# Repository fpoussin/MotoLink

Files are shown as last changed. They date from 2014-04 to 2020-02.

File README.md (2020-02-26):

View this project on [CADLAB.io](https://cadlab.io/node/808). 

MotoLink
===================

 
Build Status (https://jenkins.netyxia.net/job/MotoLink/job/master/) 
 
  

CAN Bus, K-Line interface for motorcycles, with a fuel/ignition mapper function.  

Primarily intended to communicate with Honda HRC, Generic OBD, or Yamaha YEC ECUs.  

This device will create a fuel map based on the various sensor inputs. You will then be able to alter the fuel using your prefered application. (HRC, TuneEcu, YEC, etc...)  
This replaces auto tune fuel systems like Bazzaz or Power commander, except you still have to enter the changes manually. (import/export functions are planned)  
Having a wideband exhaust sensor is mandatory. If your bike doesn't have one, you can use an innovate LC2.  

Includes some digital (RPM, Speed), analog (TPS, ECT, Wideband), serial (Wideband), as well as a knock sensor input interface for tuning.



(https://www.youtube.com/watch?v=rAnS-8KSQrY)

### File tree:  
**├── Board**  *Eagle board files*  
**├── Code**  
**│   ├── App**  *Motolink's MCU code*  
**│   ├── Bootloader**  *STM32 Bootloader*  
**│   ├── ChibiOS-RT**  *ChibiOS/RT submodule*  
**│   ├── ChibiOS-Contrib**  *ChibiOS Community drivers submodule*  
**│   └── Common**  *Common files for bootloader and Motolink*  
**├── Drivers**  *Windows drivers installer*  
**├── GUI**  *Motolink's graphical user interface*  
**├── LICENSE**  *GPL Licence file*  
**└── README.md**  *This readme file*  

You will need to init and update the git submodules (QtUsb, ChibiOS-RT, ChibiOS-Contrib) to build the projects.

## Building
### GUI
* Make sure submodules are pulled
* You will need python 2/3 in the path (system path or Qt Creator project setting PATH variable)
* Go to the GUI folder
* Unzip res/oxygen.zip
* You need a binary file of the firmware, an empty one can be created for testing. (../code/app/build/motolink.bin)
* You need to install QtUsb (https://github.com/fpoussin/QtUsb)
* Open the project with Qt Creator
* Compile and launch

### App and Bootloader
* [You will need ARM's GCC toolchain](https://developer.arm.com/open-source/gnu-toolchain/gnu-rm/downloads)
* Make sure submodules are pulled
* Go the de code/app or code/bootloader folder
* For the app, you need to compile the DSP lib (just launch make in the dsp_lib folder)
* make
* For the bootloader, use your favorite stlink interface [or my QSTLink2 app](https://github.com/fpoussin/QStlink2)
* Once the bootloader is running, you can update the app through the GUI

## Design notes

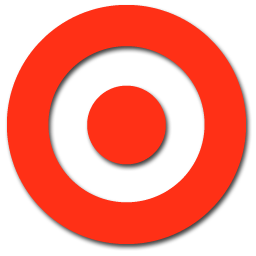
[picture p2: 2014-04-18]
GUI/res/images/target.png

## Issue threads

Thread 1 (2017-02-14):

more documentation please?

rusefi, 2017-02-14:
I've read the title page https://github.com/fpoussin/MotoLink but I am still not sure what this is and what is the status of this project.

Is this an auto-tuning software with an stm32 device as a CAN bridge? What CAN protocols do you currently support?

fpoussin, 2017-02-14:
It's an interface for aftermarket motorcycle (but works for cars too) ECU. It allows for auto mapping while looking for AFR and knock, there's a LIN interface for Hondas, the CAN interface is for some other brands but I haven't tested it (except hardware) so it's unused.

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

rusefi, 2017-02-15:
Can you please elaborate on CAN firmware capabilities? I am interested to learn more about specific protocols.

Is it untested because you do not have a CAN vehicle to test with? My truck has CAN OBD.

fpoussin, 2017-02-15:
Right now there is none as my race bike ECU (Honda) does not communicate at all during run, I use signals from the sensors directly. It have plans to test it on a modern Yamaha (MT-10) which uses a specific protocol. I also need to test on OBD CAN. (maybe on a simulator)

rusefi, 2017-02-15:
Can you point me at your OBD code?

fpoussin, 2017-02-15:
As I said it's not there yet (except basic init of the peripheral)
Sadly I don't have CAN on my car...

You can have a look at some other code here: https://github.com/ObdDiag-Net/allpro/blob/master/src/adapter/obd/isocan.cpp
https://github.com/brendan-w/python-OBD/blob/master/obd/protocols/protocol_can.py
https://en.wikipedia.org/wiki/OBD-II_PIDs#CAN_.2811-bit.29_bus_format

It's mostly a matter of setting the CAN filters, sending PIDs an reading the answer, it should be easy.

rusefi, 2017-02-15:
Thank you! Will check these links.

PS: just to be pedantic - the way I read it sounded as "not tested".

fpoussin, 2017-02-16:
You're welcome!

I'll add some code for the CAN protocols soon but I have no way to test it on a car, I also need to get an adapter to reverse engineer Yamaha's protocol.

fpoussin, 2017-02-16:
I added some basic canbus code here if you want to check.
https://github.com/fpoussin/MotoLink/blob/master/code/app/canbus.c

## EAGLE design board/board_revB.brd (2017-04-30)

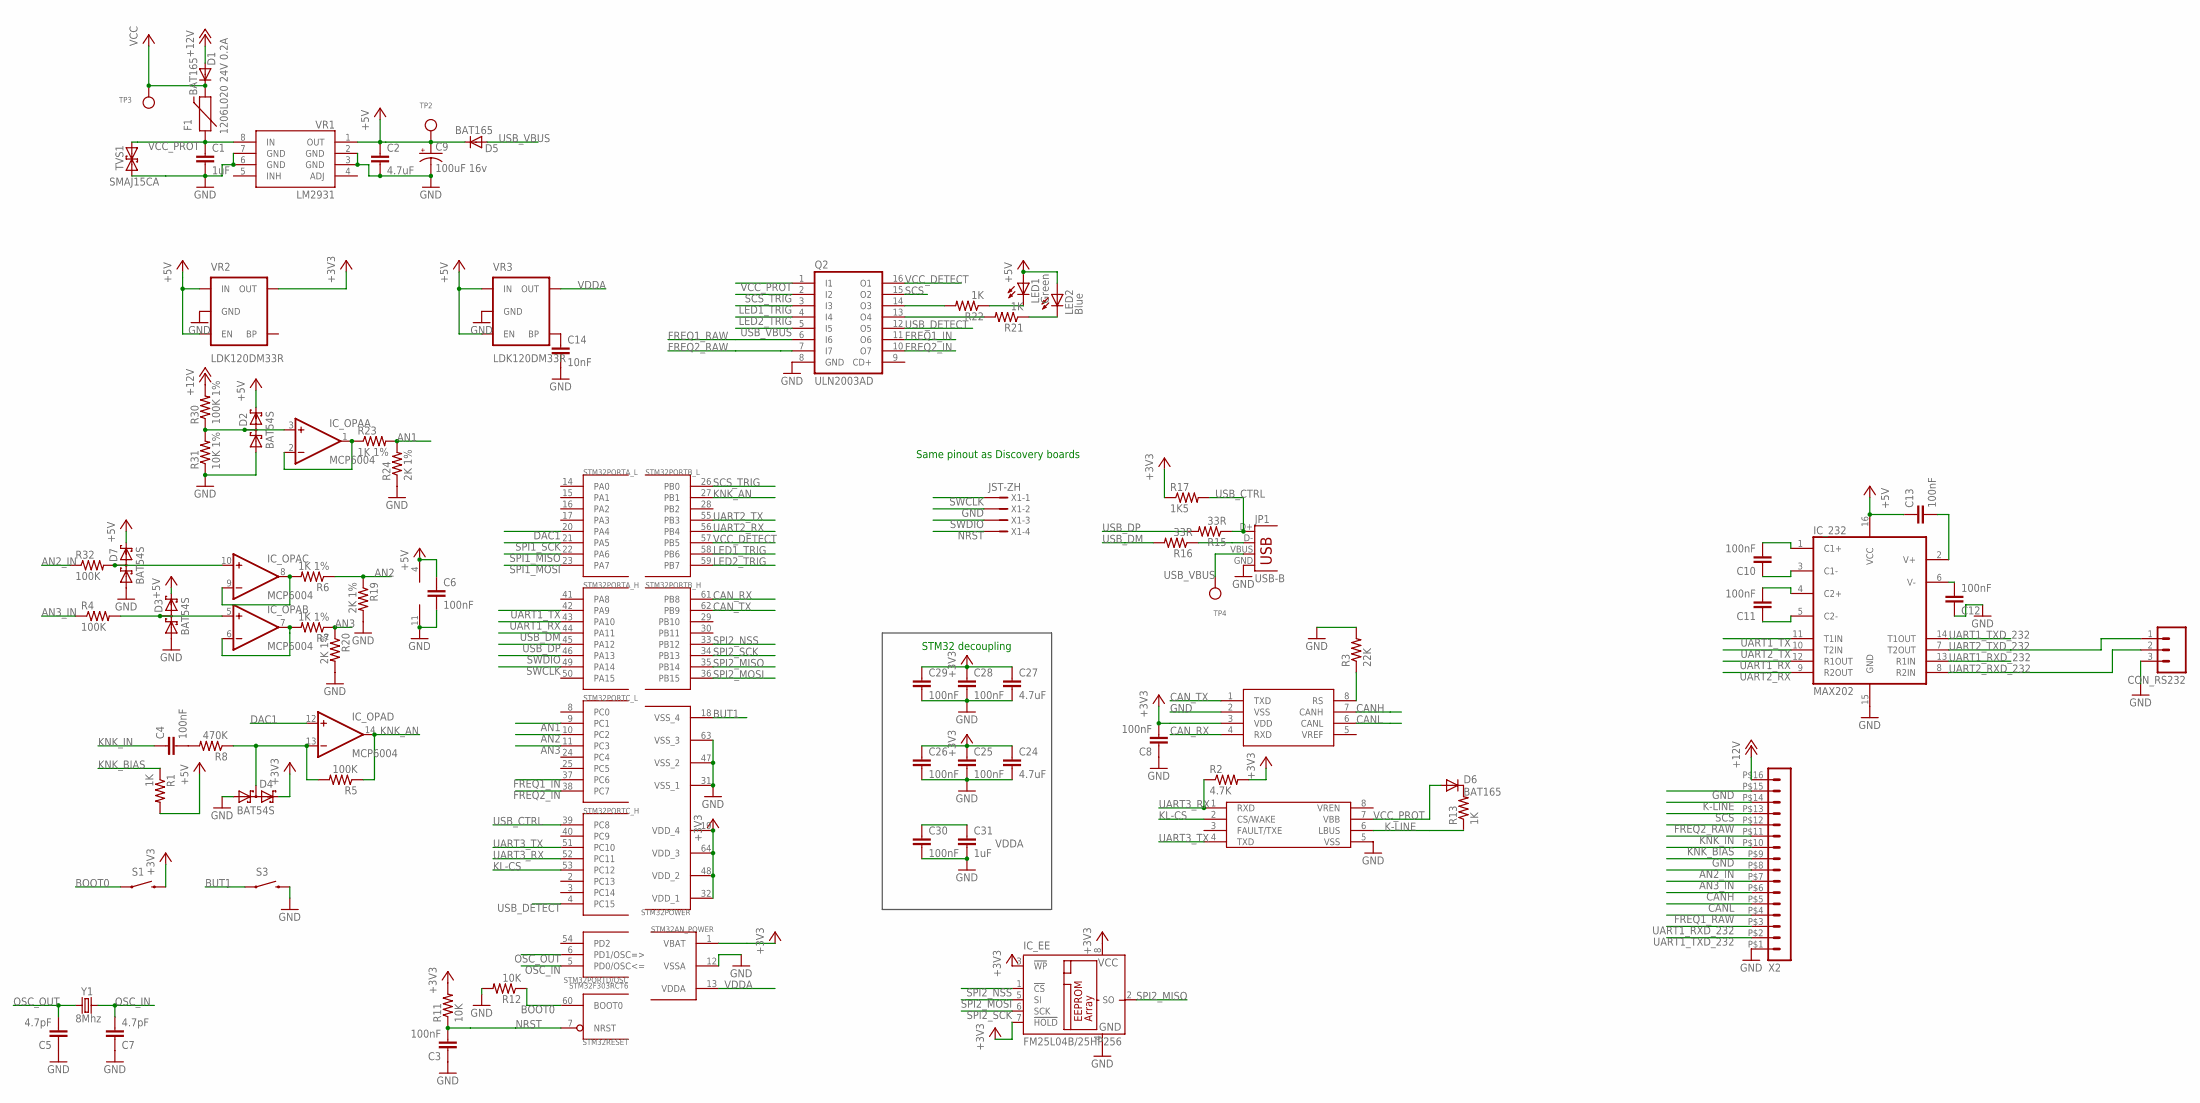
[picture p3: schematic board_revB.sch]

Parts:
C1, C31: 1uF; 0603-CAP
C2, C24, C27: 4.7uF; 0603-CAP
C3, C4, C6, C8, C10, C11, C12, C13, C25, C26, C28, C29, C30: 100nF; 0603-CAP
C5, C7: 4.7pF; 0603-CAP
C9: 100uF 16v; CPOL-RADIAL-10UF-25V
C14: 10nF; 0603-CAP
CON_RS232: M03LOCK; 1X03_LOCK
D1, D5, D6: BAT165; SOD-323
D2, D3, D4, D7: BAT54S; SOT23
F1: 1206L020 24V 0.2A; PTC-1206
IC_232: MAX202; TSSOP16
IC_CAN: MAX3051; SO08
IC_EE: FM25L04B/25HP256; SO-08
IC_KLINE: TJA1027; SO08
IC_OPA: MCP6004; TSSOP14
JP1: USB-B; USB-B-PTH
LED1: Green; LED3MM
LED2: Blue; LED3MM
Q2: ULN2003AD; SO16
R1, R13, R21, R22: 1K; 0603-RES
R2: 4.7K; 0603-RES
R3: 22K; 0603-RES
R4, R5, R32: 100K; 0603-RES
R6, R7, R23: 1K 1%; 0603-RES
R8: 470K; 0603-RES
R11, R12: 10K; 0603-RES
R15, R16: 33R; 0603-RES
R17: 1K5; 0603-RES
R19, R20, R24: 2K 1%; 0603-RES
R30: 100K 1%; 0603-RES
R31: 10K 1%; 0603-RES
S1: SWITCH-MOMENTARY-2SMD-4; TACTILE_SWITCH_TALL
S3: SWITCH-MOMENTARY-2SIDE_EZ; TACTILE-PTH-SIDEEZ
STM32: STM32F303RCT6; TQFP64
TP2, TP3, TP4: TESTPOINTROUND1MM; TESTPOINT_ROUND_1MM
TVS1: SMAJ15CA; SMA-DIODE
VR1: LM2931; SO08
VR2, VR3: LDK120DM33R; SOT23-5
X1: JST-ZH; S4B-ZR
X2: HEADER_POS16_43045-1600; 43045-1600
Y1: 8Mhz; HC49US

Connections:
+3V3: C8.2, C24.1, C25.1, C26.1, C27.1, C28.1, C29.1, D4.2 (C2), IC_CAN.3 (VDD), IC_EE.3 (!WP), IC_EE.7 (!HOLD), IC_EE.8 (VCC), R2.2, R11.2, R17.1, S1.B2 (2), STM32.1 (VBAT), STM32.19 (VDD_4), STM32.32 (VDD_1), STM32.48 (VDD_2), STM32.64 (VDD_3), VR2.5 (OUT)
+5V: C2.1, C6.1, C9.1 (+), C13.1, D2.2 (C2), D3.2 (C2), D5.1 (C), D7.2 (C2), IC_232.16 (VCC), IC_OPA.4 (V+), LED1.A, LED2.A, R1.2, TP2.P$1, VR1.1 (OUT), VR2.1 (IN), VR2.3 (EN), VR3.1 (IN), VR3.3 (EN)
+12V: D1.2 (A), R30.2, X2.P$16 (16)
AN1: R23.2, R24.2, STM32.9 (PC1)
AN1_N: IC_OPA.1 (OUT), IC_OPA.2 (-IN), R23.1
AN2: R6.1, R19.1, STM32.10 (PC2)
AN2_IN: R32.1, X2.P$8 (8)
AN2_N: IC_OPA.8 (OUT), IC_OPA.9 (-IN), R6.2
AN3: R7.1, R20.1, STM32.11 (PC3)
AN3_IN: R4.1, X2.P$7 (7)
AN3_N: IC_OPA.6 (-IN), IC_OPA.7 (OUT), R7.2
BOOT0: R12.1, S1.A2 (1), STM32.60 (BOOT0)
BUT1: S3.1, STM32.18 (VSS_4)
CANH: IC_CAN.7 (CANH), X2.P$6 (6)
CANL: IC_CAN.6 (CANL), X2.P$5 (5)
CAN_RX: IC_CAN.4 (RXD), STM32.61 (PB8)
CAN_TX: IC_CAN.1 (TXD), STM32.62 (PB9)
DAC1: IC_OPA.12 (+IN), STM32.20 (PA4)
FREQ1_IN: Q2.11 (O6), STM32.37 (PC6)
FREQ1_RAW: Q2.6 (I6), X2.P$4 (4)
FREQ2_IN: Q2.10 (O7), STM32.38 (PC7)
FREQ2_RAW: Q2.7 (I7), X2.P$12 (12)
GND: C1.2, C2.2, C3.1, C5.1, C6.2, C7.1, C8.1, C9.2 (-), C12.1, C14.2, C24.2, C25.2, C26.2, C27.2, C28.2, C29.2, C30.2, C31.2, CON_RS232.3, D2.1 (A1), D3.1 (A1), D4.1 (A1), D7.1 (A1), IC_232.15 (GND), IC_CAN.2 (VSS), IC_EE.4 (GND), IC_KLINE.5 (VSS), IC_OPA.11 (V-), JP1.GND, Q2.8 (GND), R3.2, R12.2, R19.2, R20.2, R24.1, R31.1, S3.2, STM32.12 (VSSA), STM32.31 (VSS_1), STM32.47 (VSS_2), STM32.63 (VSS_3), TVS1.A (1), VR1.2 (GND), VR1.3 (GND), VR1.6 (GND), VR1.7 (GND), VR2.2 (GND), VR3.2 (GND), X1.2, X2.P$1 (1), X2.P$9 (9), X2.P$15 (15)
K-LINE: IC_KLINE.6 (LBUS), R13.1, X2.P$14 (14)
KL-CS: IC_KLINE.2 (CS/WAKE), STM32.53 (PC12)
KNK_AN: IC_OPA.14 (OUT), R5.1, STM32.27 (PB1)
KNK_BIAS: R1.1, X2.P$10 (10)
KNK_IN: C4.1, X2.P$11 (11)
LED1_TRIG: Q2.3 (I3), STM32.58 (PB6)
LED2_TRIG: Q2.4 (I4), STM32.59 (PB7)
unnamed: D4.3 (C1A2), IC_OPA.13 (-IN), R5.2, R8.1
unnamed: D3.3 (C1A2), IC_OPA.5 (+IN), R4.2
unnamed: C4.2, R8.2
unnamed: IC_CAN.8 (RS), R3.1
unnamed: C14.1, VR3.4 (BP)
unnamed: LED2.K (C), R21.1
unnamed: Q2.13 (O4), R21.2
unnamed: D6.1 (C), R13.2
unnamed: Q2.14 (O3), R22.2
unnamed: JP1.D-, R16.1
unnamed: LED1.K (C), R22.1
unnamed: C11.2, IC_232.4 (C2+)
unnamed: C11.1, IC_232.5 (C2-)
unnamed: C10.1, IC_232.3 (C1-)
unnamed: D2.3 (C1A2), IC_OPA.3 (+IN), R30.1, R31.2
unnamed: D7.3 (C1A2), IC_OPA.10 (+IN), R32.2
unnamed: C10.2, IC_232.1 (C1+)
unnamed: C12.2, IC_232.6 (V-)
unnamed: C13.2, IC_232.2 (V+)
NRST: C3.2, R11.1, STM32.7 (NRST), X1.4
OSC_IN: C7.2, STM32.5 (PD0/OSC<=), Y1.2
OSC_OUT: C5.2, STM32.6 (PD1/OSC=>), Y1.1
SCS: Q2.15 (O2), X2.P$13 (13)
SCS_TRIG: Q2.2 (I2), STM32.26 (PB0)
SPI1_MISO: STM32.22 (PA6)
SPI1_MOSI: STM32.23 (PA7)
SPI1_SCK: STM32.21 (PA5)
SPI2_MISO: IC_EE.2 (SO), STM32.35 (PB14)
SPI2_MOSI: IC_EE.5 (SI), STM32.36 (PB15)
SPI2_NSS: IC_EE.1 (!CS), STM32.33 (PB12)
SPI2_SCK: IC_EE.6 (SCK), STM32.34 (PB13)
SWCLK: STM32.49 (PA14), X1.1
SWDIO: STM32.46 (PA13), X1.3
UART1_RX: IC_232.12 (R1OUT), STM32.43 (PA10)
UART1_RXD_232: IC_232.13 (R1IN), X2.P$3 (3)
UART1_TX: IC_232.11 (T1IN), STM32.42 (PA9)
UART1_TXD_232: IC_232.14 (T1OUT), X2.P$2 (2)
UART2_RX: IC_232.9 (R2OUT), STM32.56 (PB4)
UART2_RXD_232: CON_RS232.2, IC_232.8 (R2IN)
UART2_TX: IC_232.10 (T2IN), STM32.55 (PB3)
UART2_TXD_232: CON_RS232.1, IC_232.7 (T2OUT)
UART3_RX: IC_KLINE.1 (RXD), R2.1, STM32.52 (PC11)
UART3_TX: IC_KLINE.4 (TXD), STM32.51 (PC10)
USB_CTRL: JP1.D+, R15.1, R17.2, STM32.39 (PC8)
USB_DETECT: Q2.12 (O5), STM32.4 (PC15)
USB_DM: R16.2, STM32.44 (PA11)
USB_DP: R15.2, STM32.45 (PA12)
USB_VBUS: D5.2 (A), JP1.VBUS, Q2.5 (I5), TP4.P$1
VCC: D1.1 (C), F1.2, TP3.P$1
VCC_DETECT: Q2.16 (O1), STM32.57 (PB5)
VCC_PROT: C1.1, D6.2 (A), F1.1, IC_KLINE.7 (VBB), Q2.1 (I1), TVS1.C (2), VR1.8 (IN)
VDDA: C30.1, C31.1, STM32.13 (VDDA), VR3.5 (OUT)

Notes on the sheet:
STM32 decoupling
Same pinout as Discovery boards

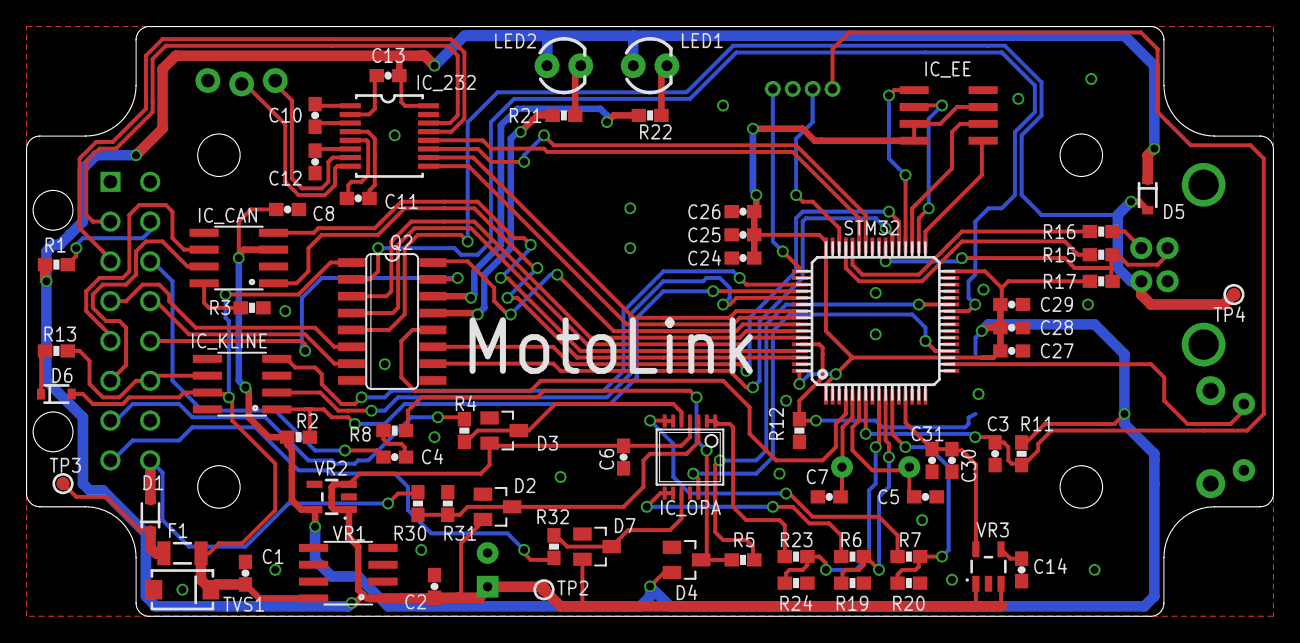
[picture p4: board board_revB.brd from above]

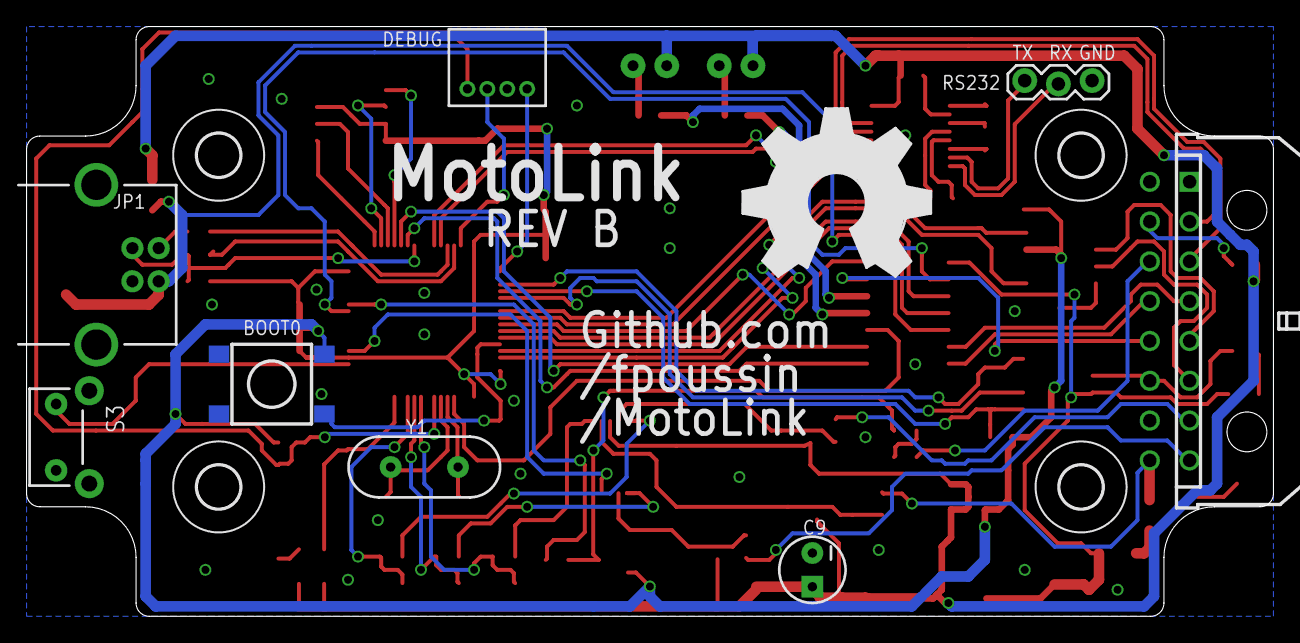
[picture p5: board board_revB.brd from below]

Board: 2 copper layers, 94.0 x 44.5 mm, 81 parts (13 on the bottom side), 79 nets.

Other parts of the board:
U$2, U$3, U$4, U$5: 3,2
U$6: OSHW_FILLX500_NOTEXT

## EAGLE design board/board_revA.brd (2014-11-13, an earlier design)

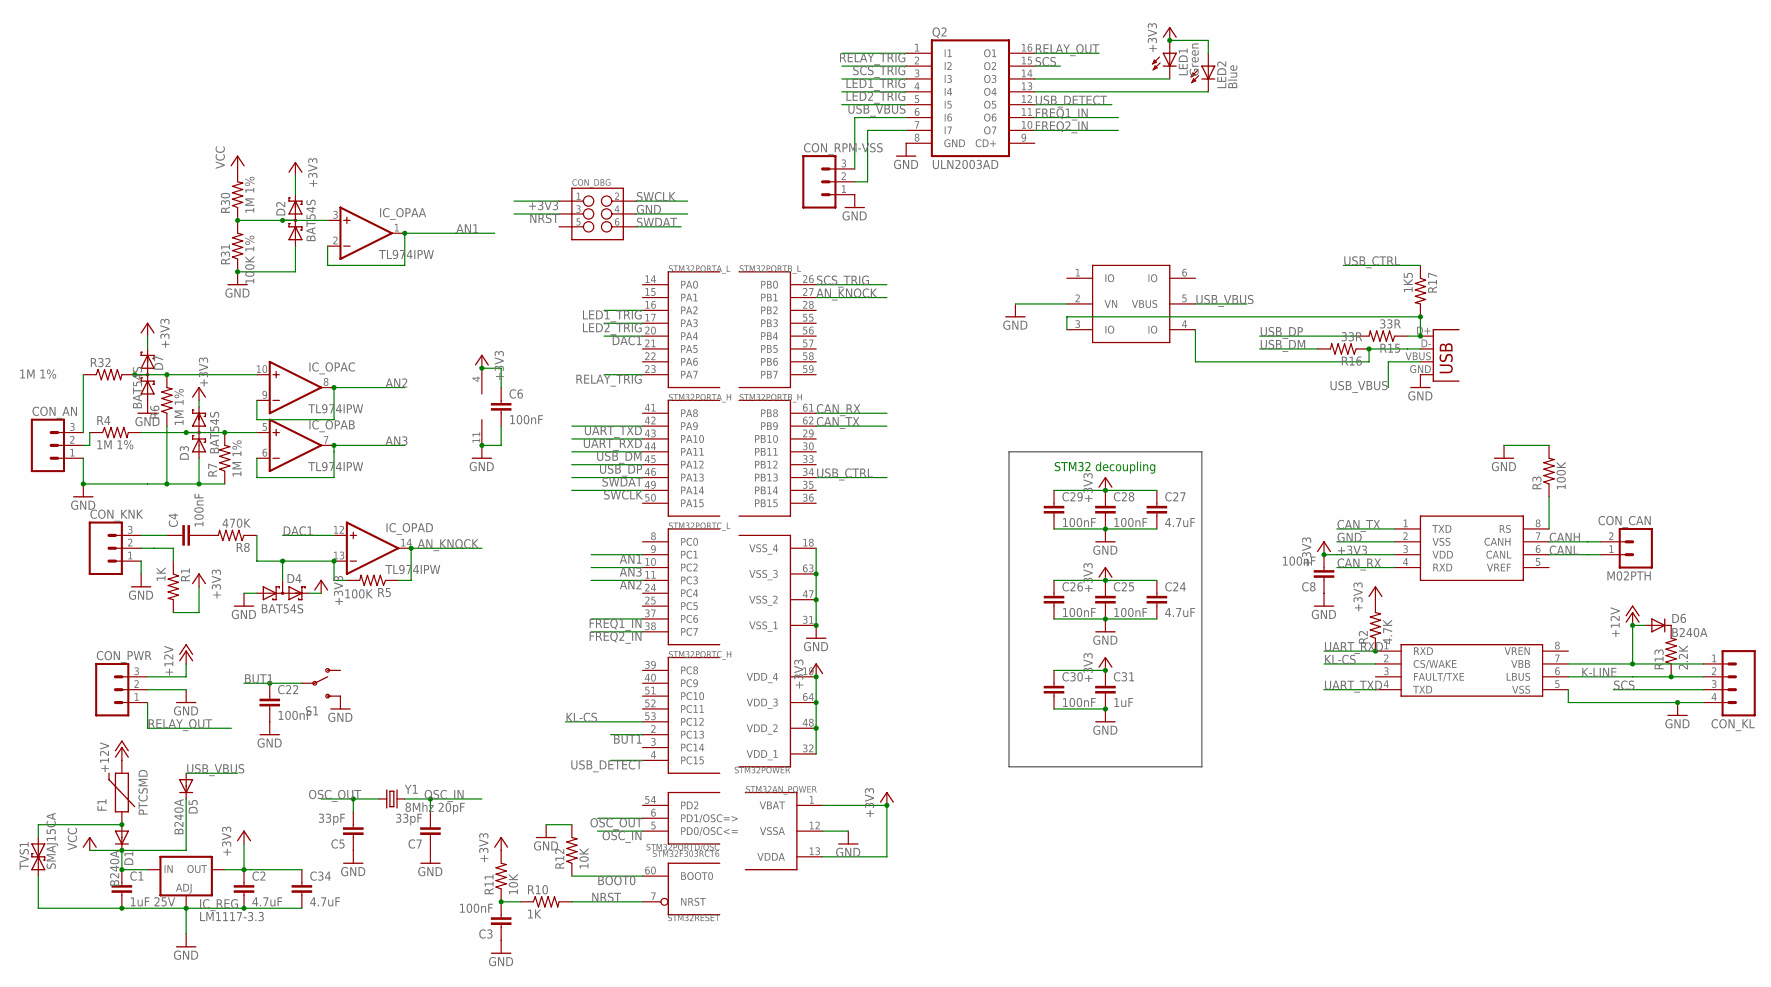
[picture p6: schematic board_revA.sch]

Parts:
C1: 1uF 25V; 0603-CAP
C2, C24, C27, C34: 4.7uF; 0603-CAP
C3, C4, C6, C8, C22, C25, C26, C28, C29, C30: 100nF; 0603-CAP
C5, C7: 33pF; 0603-CAP
C31: 1uF; 0603-CAP
CON_AN: M03PTH; 1X03
CON_CAN: M02PTH; 1X02
CON_DBG: M03X22X3_SILK_SM; 2X3
CON_KL: M04PTH; 1X04
CON_KNK: M03PTH; 1X03
CON_PWR: M03PTH; 1X03
CON_RPM-VSS: M03PTH; 1X03
CON_USB: USBSMD; USB-MINIB
D1, D5, D6: B240A; SMA-DIODE
D2, D3, D4, D7: BAT54S; SOT23
F1: PTCSMD; PTC-1206
IC_CAN: MAX3051; SO08
IC_KLINE: MCP2004; SO08
IC_OPA: TL974IPW; TSSOP14
IC_REG: LM1117-3.3; DPACK
LED1: Green; LED3MM
LED2: Blue; LED3MM
Q2: ULN2003AD; SO16
R1, R10: 1K; 0603-RES
R2: 4.7K; 0603-RES
R3, R5: 100K; 0603-RES
R4, R6, R7, R30, R32: 1M 1%; 0603-RES
R8: 470K; 0603-RES
R11, R12: 10K; 0603-RES
R13: 2.2K; 0603-RES
R15, R16: 33R; 0603-RES
R17: 1K5; 0603-RES
R31: 100K 1%; 0603-RES
S1: SWITCH-SPDTPTH; SWITCH-SPDT
STM32: STM32F303RCT6; TQFP64
TVS1: SMAJ15CA; SMA-DIODE
TVS2: NUP4201MR6; SOT23-6
Y1: 8Mhz 20pF; HC49US

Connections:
+3V3: C2.1, C6.1, C8.2, C24.1, C25.1, C26.1, C27.1, C28.1, C29.1, C30.1, C31.1, C34.1, CON_DBG.1, D2.2 (C2), D3.2 (C2), D4.2 (C2), D7.2 (C2), IC_CAN.3 (VDD), IC_OPA.4 (V+), IC_REG.4 (OUT), LED1.A, LED2.A, R1.2, R2.2, R11.2, STM32.1 (VBAT), STM32.13 (VDDA), STM32.19 (VDD_4), STM32.32 (VDD_1), STM32.48 (VDD_2), STM32.64 (VDD_3)
+12V: CON_KL.1, CON_PWR.3, D6.A, F1.2, IC_KLINE.7 (VBB)
AN1: IC_OPA.1 (OUT), IC_OPA.2 (-IN), STM32.9 (PC1)
AN2: IC_OPA.8 (OUT), IC_OPA.9 (-IN), STM32.11 (PC3)
AN3: IC_OPA.6 (-IN), IC_OPA.7 (OUT), STM32.10 (PC2)
AN_KNOCK: IC_OPA.14 (OUT), R5.1, STM32.27 (PB1)
BOOT0: R12.1, STM32.60 (BOOT0)
BUT1: C22.1, S1.2, STM32.2 (PC13)
CANH: CON_CAN.2, IC_CAN.7 (CANH)
CANL: CON_CAN.1, IC_CAN.6 (CANL)
CAN_RX: IC_CAN.4 (RXD), STM32.61 (PB8)
CAN_TX: IC_CAN.1 (TXD), STM32.62 (PB9)
DAC1: IC_OPA.12 (+IN), STM32.20 (PA4)
FREQ1_IN: Q2.11 (O6), STM32.37 (PC6)
FREQ2_IN: Q2.10 (O7), STM32.38 (PC7)
GND: C1.2, C2.2, C3.1, C5.1, C6.2, C7.1, C8.1, C22.2, C24.2, C25.2, C26.2, C27.2, C28.2, C29.2, C30.2, C31.2, C34.2, CON_AN.1, CON_DBG.4, CON_KL.4, CON_KNK.1, CON_PWR.2, CON_RPM-VSS.1, CON_USB.GND, D2.1 (A1), D3.1 (A1), D4.1 (A1), D7.1 (A1), IC_CAN.2 (VSS), IC_KLINE.5 (VSS), IC_OPA.11 (V-), IC_REG.1 (ADJ), Q2.8 (GND), R3.2, R6.1, R7.1, R12.2, R31.1, S1.3 (S), STM32.12 (VSSA), STM32.18 (VSS_4), STM32.31 (VSS_1), STM32.47 (VSS_2), STM32.63 (VSS_3), TVS1.A (1), TVS2.2 (VN)
K-LINE: CON_KL.2, IC_KLINE.6 (LBUS), R13.1
KL-CS: IC_KLINE.2 (CS/WAKE), STM32.53 (PC12)
LED1_TRIG: Q2.3 (I3), STM32.16 (PA2)
LED2_TRIG: Q2.4 (I4), STM32.17 (PA3)
unnamed: CON_KNK.2, R1.1
unnamed: CON_AN.3, R32.1
unnamed: CON_AN.2, R4.1
unnamed: C4.1, CON_KNK.3
unnamed: D3.3 (C1A2), IC_OPA.5 (+IN), R4.2, R7.2
unnamed: C4.2, R8.2
unnamed: CON_USB.D+, R15.1, R17.2, TVS2.3 (IO)
unnamed: IC_CAN.8 (RS), R3.1
unnamed: D1.A, F1.1, TVS1.C (2)
unnamed: LED1.K (C), Q2.14 (O3)
unnamed: LED2.K (C), Q2.13 (O4)
unnamed: D4.3 (C1A2), IC_OPA.13 (-IN), R5.2, R8.1
unnamed: D6.C, R13.2
unnamed: CON_RPM-VSS.3, Q2.6 (I6)
unnamed: CON_USB.D-, R16.1, TVS2.4 (IO)
unnamed: C3.2, R10.1, R11.1
unnamed: CON_RPM-VSS.2, Q2.7 (I7)
unnamed: D2.3 (C1A2), IC_OPA.3 (+IN), R30.1, R31.2
unnamed: D7.3 (C1A2), IC_OPA.10 (+IN), R6.2, R32.2
NRST: CON_DBG.3, R10.2, STM32.7 (NRST)
OSC_IN: C7.2, STM32.5 (PD0/OSC<=), Y1.2
OSC_OUT: C5.2, STM32.6 (PD1/OSC=>), Y1.1
RELAY_OUT: CON_PWR.1, Q2.16 (O1)
RELAY_TRIG: Q2.1 (I1), STM32.23 (PA7)
SCS: CON_KL.3, Q2.15 (O2)
SCS_TRIG: Q2.2 (I2), STM32.26 (PB0)
SWCLK: CON_DBG.2, STM32.49 (PA14)
SWDAT: CON_DBG.6, STM32.46 (PA13)
UART_RXD: IC_KLINE.1 (RXD), R2.1, STM32.43 (PA10)
UART_TXD: IC_KLINE.4 (TXD), STM32.42 (PA9)
USB_CTRL: R17.1, STM32.34 (PB13)
USB_DETECT: Q2.12 (O5), STM32.4 (PC15)
USB_DM: R16.2, STM32.44 (PA11)
USB_DP: R15.2, STM32.45 (PA12)
USB_VBUS: CON_USB.VBUS, D5.A, Q2.5 (I5), TVS2.5 (VBUS)
VCC: C1.1, D1.C, D5.C, IC_REG.3 (IN), R30.2

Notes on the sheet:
STM32 decoupling

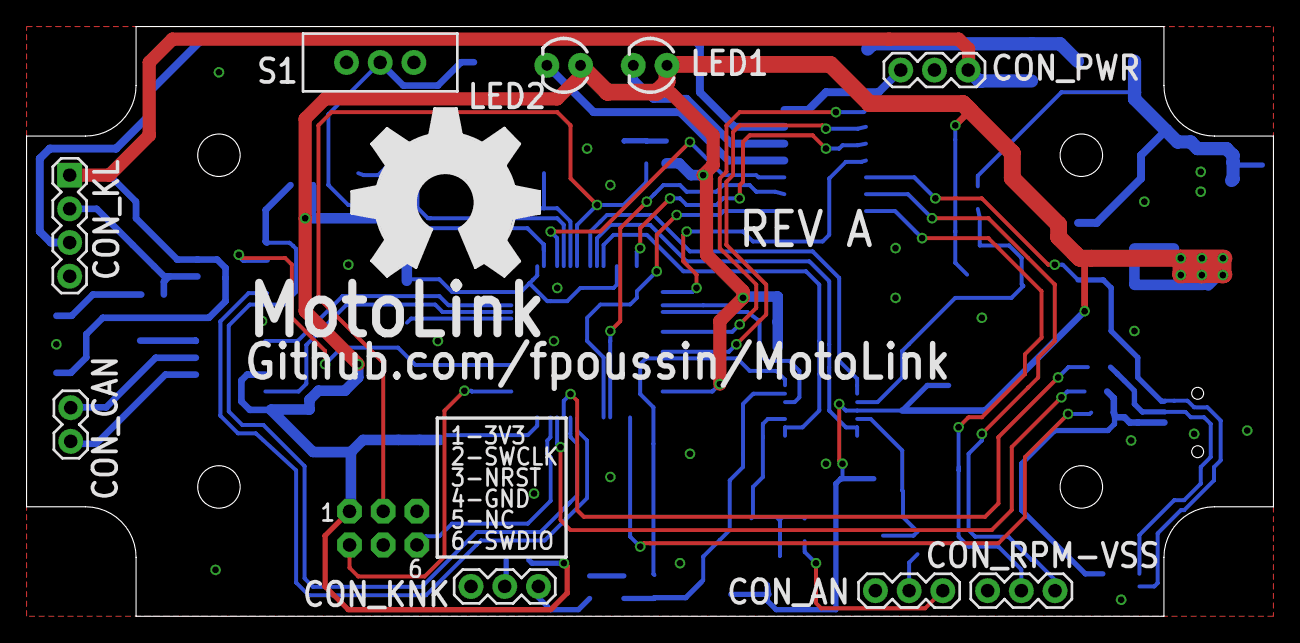
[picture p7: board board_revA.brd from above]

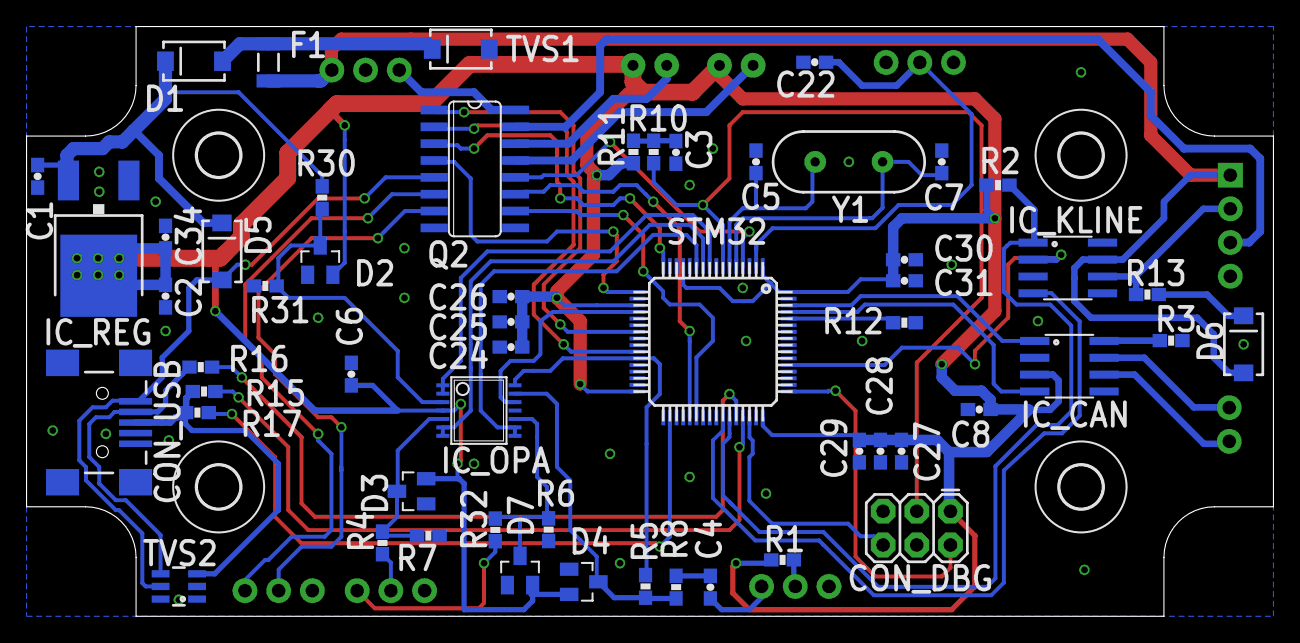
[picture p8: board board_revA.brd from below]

Board: 2 copper layers, 94.0 x 44.5 mm, 69 parts (59 on the bottom side), 56 nets.

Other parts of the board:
U$2, U$3, U$4, U$5: 3,2
U$6: OSHW_FILLX500_NOTEXT

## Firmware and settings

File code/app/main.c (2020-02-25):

/*
    ChibiOS/RT - Copyright (C) 2006-2013 Giovanni Di Sirio

    Licensed under the Apache License, Version 2.0 (the "License");
    you may not use this file except in compliance with the License.
    You may obtain a copy of the License at

        http://www.apache.org/licenses/LICENSE-2.0

    Unless required by applicable law or agreed to in writing, software
    distributed under the License is distributed on an "AS IS" BASIS,
    WITHOUT WARRANTIES OR CONDITIONS OF ANY KIND, either express or implied.
    See the License for the specific language governing permissions and
    limitations under the License.
*/

#include "ch.h"
#include "hal.h"
#include "canbus.h"
#include "arm_math.h"
#include "chprintf.h"
#include "commands.h"
#include "innovate.h"
#include "sensors.h"
#include "shell.h"
#include "storage.h"
#include "tables.h"
#include "usb_config.h"
#include <stdio.h>
#include <string.h>

/*===========================================================================*/
/* Macros                                                                    */
/*===========================================================================*/

#define SHELL_SD SDU1

/* Check if tp was the previous thread */
#define RUNNING(tp) (uint16_t)((tp == chThdGetSelfX()->newer) << 15)
#define FREQIN_INTERVAL TIME_MS2I(25)

/*===========================================================================*/
/* Thread pointers.                                                          */
/*===========================================================================*/

/*===========================================================================*/
/* Structs / Vars                                                            */
/*===========================================================================*/

uint16_t irq_pct = 0;
const char *irq_name = "Interrupts";
static virtual_timer_t vt_freqin;
extern bool dbg_can, dbg_sensors;
extern const ShellCommand sh_commands[];

/*===========================================================================*/
/* CallBacks                                                                 */
/*===========================================================================*/

/*
 * Set from bootloader, here for reference.
static const WDGConfig wdgcfg = {
  STM32_IWDG_PR_64,
  STM32_IWDG_RL(250), // 250ms
  STM32_IWDG_WIN_DISABLED
};
*/
CCM_FUNC void freqinVTHandler(void *arg) {
  (void)arg;

  reEnableInputCapture(&TIMCAPD3);

  chSysLockFromISR();
  chVTSetI(&vt_freqin, FREQIN_INTERVAL, freqinVTHandler, NULL);
  chSysUnlockFromISR();
}

static const ShellConfig shell_cfg1 = {(BaseSequentialStream *)&SHELL_SD,
                                       sh_commands};

/*===========================================================================*/
/* Configs                                                                   */
/*===========================================================================*/

const DACConfig dac1cfg1 = {2047U, DAC_DHRM_12BIT_RIGHT, 0};

// Used for MTS
SerialConfig uart1Cfg = {19200, // bit rate
                         0, USART_CR2_STOP1_BITS, 0};

// Extra header
SerialConfig uart2Cfg = {115200, // bit rate
                         0, USART_CR2_STOP1_BITS, 0};

// K-Line
SerialConfig uart3Cfg = {19200, // bit rate
                         0, USART_CR2_STOP1_BITS, 0};

PWMConfig pwmcfg = {10000, /* 10kHz PWM clock frequency.   */
                    50,    /* Initial PWM period 10mS.       */
                    NULL,
                    {{PWM_OUTPUT_ACTIVE_HIGH, NULL},
                     {PWM_OUTPUT_ACTIVE_HIGH, NULL},
                     {PWM_OUTPUT_DISABLED, NULL},
                     {PWM_OUTPUT_DISABLED, NULL}},
                    0,
                    0};

const CANConfig cancfg = {CAN_MCR_ABOM | CAN_MCR_AWUM | CAN_MCR_TXFP,
                          CAN_BTR_SJW(1) | CAN_BTR_TS2(4) | CAN_BTR_TS1(5) |
                              CAN_BTR_BRP(5)};

/*===========================================================================*/
/* Threads                                                                   */
/*===========================================================================*/

THD_WORKING_AREA(waThreadCAN, 256);
CCM_FUNC static THD_FUNCTION(ThreadCAN, arg) {
  event_listener_t el;
  CANTxFrame txmsg;
  CANRxFrame rxmsg;
  uint16_t i;
  bool pidserved;

  (void)arg;
  chRegSetThreadName("CAN Bus");

  while (CAND1.state != CAN_READY)
    chThdSleepMilliseconds(10);
  while (SDU1.state != SDU_READY)
    chThdSleepMilliseconds(10);

  chEvtRegister(&CAND1.rxfull_event, &el, 0);

  while (TRUE) {

    // Are we using coms for sensor data? If not just sleep.
    if (settings.sensorsInput != SENSORS_INPUT_COM &&
        (settings.functions & FUNC_OBD_SERVER) == 0) {

      chThdSleepMilliseconds(100);
      continue;
    }

    // checkCanFilters(&CAND1, &cancfg);

    if (chEvtWaitAnyTimeout(ALL_EVENTS, TIME_MS2I(10)) == 0) {
      continue;
    }

    while (canReceive(&CAND1, CAN_ANY_MAILBOX, &rxmsg, TIME_IMMEDIATE) ==
           MSG_OK) {
      /* Process message.*/

      if (dbg_can) {
        chprintf(DBG_STREAM, "->[CANBUS][%08x][SID:%03x][RTR:%01x]",
                 chSysGetRealtimeCounterX(), rxmsg.SID, rxmsg.RTR);
        for (i = 0; i < rxmsg.DLC; i++) {
          chprintf(DBG_STREAM, ":%02x", rxmsg.data8[i]);
        }
        chprintf(DBG_STREAM, "\r\n");
      }

      if (settings.functions & FUNC_OBD_SERVER) {

        pidserved = serveCanOBDPidRequest(&CAND1, &txmsg, &rxmsg);

        if (dbg_can && pidserved) {
          chprintf(DBG_STREAM, "<-[CANBUS][%08x][SID:%03x][RTR:%01x]",
                   chSysGetRealtimeCounterX(), txmsg.SID, txmsg.RTR);
          for (i = 0; i < txmsg.DLC; i++) {
            chprintf(DBG_STREAM, ":%02x", txmsg.data8[i]);
          }
          chprintf(DBG_STREAM, "\r\n");
        } else if (dbg_can) {
          chprintf(DBG_STREAM, "!![CANBUS][%08x][ignored sender %03x]\r\n",
                   chSysGetRealtimeCounterX(), rxmsg.SID);
        }
      }

      if ((settings.functions & FUNC_OBD_SERVER) == 0) {
        if (settings.sensorsInput == SENSORS_INPUT_OBD_CAN) {

          readCanOBDPidResponse(&rxmsg);
        } else if (settings.sensorsInput == SENSORS_INPUT_YAMAHA_CAN) {

          readCanYamahaPid(&rxmsg);
        }
      }
    }

    if (settings.sensorsInput == SENSORS_INPUT_OBD_CAN &&
        (settings.functions & FUNC_OBD_SERVER) == 0) {

      // Request OBD PIDs
      sendCanOBDFrames(&CAND1, &txmsg);

      if (dbg_can) {
        chprintf(DBG_STREAM, "<-[CANBUS][%08x][SID:%03x][RTR:%01x]",
                 chSysGetRealtimeCounterX(), txmsg.SID, txmsg.RTR);
        for (i = 0; i < 8; i++) {
          chprintf(DBG_STREAM, ":%02x", txmsg.data8[i]);
        }
        chprintf(DBG_STREAM, "\r\n");
      }
      chThdSleepMilliseconds(100); // ~10Hz
    }
  }
  chEvtUnregister(&CAND1.rxfull_event, &el);
  return;
}

/*
 * USB Bulk thread.
 */
THD_WORKING_AREA(waThreadBDU, 1024);
CCM_FUNC static THD_FUNCTION(ThreadBDU, arg) {
  event_listener_t el1;
  eventmask_t flags;
  (void)arg;
  chRegSetThreadName("BDU");

  chEvtRegisterMask(chnGetEventSource(&SDU2), &el1, ALL_EVENTS);

  while (USBD1.state != USB_READY)
    chThdSleepMilliseconds(10);
  while (SDU2.state != SDU_READY)
    chThdSleepMilliseconds(10);

  while (TRUE) {
    chEvtWaitAnyTimeout(ALL_EVENTS, TIME_IMMEDIATE);
    flags = chEvtGetAndClearFlags(&el1);

    pwmEnableChannel(&PWMD_LED2, CHN_LED2,
                     PWM_PERCENTAGE_TO_WIDTH(&PWMD_LED2, 8000));

    if (flags & CHN_INPUT_AVAILABLE) {
      pwmEnableChannel(&PWMD_LED2, CHN_LED2,
                       PWM_PERCENTAGE_TO_WIDTH(&PWMD_LED2, 1000));
      readCommand((BaseChannel *)&SDU2);
    } else
      chThdSleepMilliseconds(2);
  }
  return;
}

/*
 * USB Serial thread.
 */
THD_WORKING_AREA(waThreadSDU, 256);
THD_WORKING_AREA(waThreadShell, 512);
CCM_FUNC static THD_FUNCTION(ThreadSDU, arg) {
  (void)arg;
  uint8_t in_buffer[SERIAL_BUFFERS_SIZE];
  uint8_t out_buffer[SERIAL_BUFFERS_SIZE];
  // uint8_t buffer_check[SERIAL_BUFFERS_SIZE/2];
  size_t in, out;
  thread_t *th_shell = NULL;
  chRegSetThreadName("SDU");

  while (USBD1.state != USB_READY)
    chThdSleepMilliseconds(10);
  while (SDU1.state != SDU_READY)
    chThdSleepMilliseconds(10);
  while (SD3.state != SD_READY)
    chThdSleepMilliseconds(10);

  // Enable K-line transceiver
  palSetPad(PORT_KLINE_CS, PAD_KLINE_CS);

  shellInit();

  while (TRUE) {

    if (settings.serialMode == SERIAL_MODE_SHELL) {
      if (th_shell == NULL || chThdTerminatedX(th_shell)) {
        th_shell =
            chThdCreateStatic(waThreadShell, sizeof(waThreadShell),
                              NORMALPRIO + 1, shellThread, (void *)&shell_cfg1);
      }
      chThdSleepMilliseconds(10);
      continue;
    }

    if (settings.serialMode != SERIAL_MODE_KLINE) {
      chThdSleepMilliseconds(10);
      continue;
    }

    /* In case we stop it to change baudrate */
    while (SD3.state != SD_READY)
      chThdSleepMilliseconds(10);

    if (doKLineInit && 0) {
      sdStop(&SD3);
      klineInit(false);
      // fiveBaudInit(&SD3);
      // sdReadTimeout(&SD3, buffer_check, 1, TIME_MS2I(5)); // noise
      doKLineInit = false;
      sdStart(&SD3, &uart1Cfg);
    }

    in = chnReadTimeout(&SDU1, in_buffer, sizeof(in_buffer), TIME_IMMEDIATE);
    out = sdReadTimeout(&SD3, out_buffer, sizeof(out_buffer), TIME_IMMEDIATE);

    while (in == 0 && out == 0) {

      chThdSleepMilliseconds(1);
      in = chnReadTimeout(&SDU1, in_buffer, sizeof(in_buffer), TIME_IMMEDIATE);
      out = sdReadTimeout(&SD3, out_buffer, sizeof(out_buffer), TIME_IMMEDIATE);
    }

    if (in > 0) {
      sdWriteTimeout(&SD3, in_buffer, in, TIME_MS2I(10));
    }

    if (out > 0) {
      chnWriteTimeout(&SDU1, out_buffer, out, TIME_MS2I(10));
    }
  }
  return;
}

/*
 * Sensors thread.
 */
static pair_t an1_buffer[ADC_GRP1_BUF_DEPTH / 2];
static pair_t an2_buffer[ADC_GRP1_BUF_DEPTH / 2];
static pair_t an3_buffer[ADC_GRP1_BUF_DEPTH / 2];
THD_WORKING_AREA(waThreadADC, 256);
CCM_FUNC static THD_FUNCTION(ThreadADC, arg) {
  (void)arg;
  chRegSetThreadName("Sensors");

  adcsample_t *sensorsDataPtr;
  size_t n;
  uint32_t i, pos;
  uint32_t an[3] = {0, 0, 0};
  median_t an1, an2, an3;
  uint8_t row, col;

  chThdSleepMilliseconds(250);
  timcapEnable(&TIMCAPD3);
  chVTSet(&vt_freqin, FREQIN_INTERVAL, freqinVTHandler, NULL);
  adcStartConversion(&ADCD1, &adcgrpcfg_sensors, samples_sensors,
                     ADC_GRP1_BUF_DEPTH);

  median_init(&an1, 0, an1_buffer, ADC_GRP1_BUF_DEPTH / 2);
  median_init(&an2, 0, an2_buffer, ADC_GRP1_BUF_DEPTH / 2);
  median_init(&an3, 0, an3_buffer, ADC_GRP1_BUF_DEPTH / 2);

  while (TRUE) {
    while (!recvFreeSamples(&sensorsMb, (void *)&sensorsDataPtr, &n))
      chThdSleepMilliseconds(5);

    an[0] = 0;
    an[1] = 0;
    an[2] = 0;

    /* Filtering and adding */
    for (i = 0; i < (n / ADC_GRP1_NUM_CHANNELS); i++) {
      pos = i * ADC_GRP1_NUM_CHANNELS;
      an[0] += median_filter(&an1, sensorsDataPtr[pos]);
      an[1] += median_filter(&an2, sensorsDataPtr[pos + 1]);
      an[2] += median_filter(&an3, sensorsDataPtr[pos + 2]);
    }

    /* Averaging */
    an[0] /= (n / ADC_GRP1_NUM_CHANNELS);
    an[1] /= (n / ADC_GRP1_NUM_CHANNELS);
    an[2] /= (n / ADC_GRP1_NUM_CHANNELS);

    /* Convert to milliVolts */
    an[0] *= VBAT_RATIO;
    an[1] *= AN_RATIO;
    an[2] *= AN_RATIO;

    sensors_data.an1 = an[0];
    sensors_data.an2 = an[1];
    sensors_data.an3 = an[2];

    /* Analog/Digital Sensors */
    if (settings.sensorsInput == SENSORS_INPUT_DIRECT) {
      sensors_data.tps = calculateTpFromMillivolt(
          settings.tpsMinV, settings.tpsMaxV, sensors_data.an2);
      sensors_data.rpm =
          calculateFreqWithRatio(sensors_data.freq1, settings.rpmMult);
      sensors_data.spd =
          calculateFreqWithRatio(sensors_data.freq2, settings.spdMult);
    } else if (settings.sensorsInput == SENSORS_INPUT_TEST) {
      sensors_data.tps = rand16(0, 200);
      sensors_data.rpm = rand16(10, 18000);
      sensors_data.spd = rand16(5, 10000);
    }

    /* AFR */
    if (settings.afrInput == AFR_INPUT_AN) {
      sensors_data.afr = calculateAFRFromMillivolt(
          settings.AfrMinVal, settings.AfrMaxVal, sensors_data.an3);
    } else if (settings.afrInput == AFR_INPUT_TEST) {
      sensors_data.afr = rand16(11000, 16000) / 100;
    }

    if (dbg_sensors) {
      chprintf(DBG_STREAM, "->[SENSORS] TPS mV/PCT: %06u/%04u\r\n",
               sensors_data.an2, sensors_data.tps);
      chprintf(DBG_STREAM, "->[SENSORS] RMP Hz/Mult/Val: %06u/%.4f/%04u\r\n",
               sensors_data.freq1, settings.rpmMult, sensors_data.rpm);
      chprintf(DBG_STREAM, "->[SENSORS] SPD Hz/Mult/Val: %06u/%.4f/%04u\r\n",
               sensors_data.freq2, settings.spdMult, sensors_data.spd);
    }

    if (findCell(sensors_data.tps / 2, sensors_data.rpm, &row, &col)) {
      sensors_data.cell.row = row;
      sensors_data.cell.col = col;
      if (dbg_sensors) {
        chprintf(DBG_STREAM,
                 "->[SENSORS] Row:Value/Col:Value: %02u:%05u/%02u:%05u\r\n",
                 row, tableRows[row], col, tableColumns[col] * 100);
      }

      if ((settings.functions & FUNC_RECORD) && sensors_data.rpm != 0) {
        /* Average */
        tableAFR[row][col] =
            tableAFR[row][col] == 0
                ? sensors_data.afr
                : ((uint16_t)sensors_data.afr + (uint16_t)tableAFR[row][col]) /
                      2;
        /* Peaks */
        tableKnock[row][col] = sensors_data.knock_value > tableKnock[row][col]
                                   ? sensors_data.knock_value
                                   : tableKnock[row][col];
      }
    }
  }
  return;
}

/*
 * Knock processing thread.
 */
static float32_t input[FFT_SIZE * 2];
static float32_t output[FFT_SIZE * 2];
static float32_t mag_knock[FFT_SIZE / 2];
THD_WORKING_AREA(waThreadKnock, 600);
CCM_FUNC static THD_FUNCTION(ThreadKnock, arg) {
  (void)arg;
  chRegSetThreadName("Knock");

  q15_t *knockDataPtr;
  size_t knockDataSize;

  float32_t maxValue = 0;
  uint32_t maxIndex = 0;
  uint16_t i;

  /* ADC 3 Ch1 Offset. -2048 */
  ADC3->OFR1 =
      ADC_OFR1_OFFSET1_EN | ((1 << 26) & ADC_OFR1_OFFSET1_CH) | (2048 & 0xFFF);
  dacPutChannelX(&DACD1, 0,
                 2048); // This sets the offset for the knock ADC opamp.

  chThdSleepMilliseconds(200);
  adcStartConversion(&ADCD3, &adcgrpcfg_knock, samples_knock,
                     ADC_GRP2_BUF_DEPTH);

  /* Initialize the CFFT/CIFFT module */
  arm_rfft_fast_instance_f32 S1;
  arm_rfft_fast_init_f32(&S1, FFT_SIZE);

  while (TRUE) {
    while (!recvFreeSamples(&knockMb, (void *)&knockDataPtr, &knockDataSize))
      chThdSleepMilliseconds(2);

    /* Copy and convert ADC samples */
    for (i = 0; i < FFT_SIZE * 2; i += 4) {
      /* Hann Window */
      float32_t multiplier =
          (1.0 - arm_cos_f32((2.0 * PI * (float32_t)i) /
                             (((float32_t)FFT_SIZE * 2.0) - 1.0)));
      input[i] = multiplier * (float32_t)knockDataPtr[i];
      input[i + 1] = multiplier * (float32_t)knockDataPtr[i + 1];
      input[i + 2] = multiplier * (float32_t)knockDataPtr[i + 2];
      input[i + 3] = multiplier * (float32_t)knockDataPtr[i + 3];
    }

    /* Process the data through the RFFT module */
    arm_rfft_fast_f32(&S1, input, output, 0);

    /* Process the data through the Complex Magnitude Module for
    calculating the magnitude at each bin */
    arm_cmplx_mag_f32(output, mag_knock,
                      FFT_SIZE / 2); // Calculate magnitude, outputs q2.14
    arm_max_f32(mag_knock, FFT_SIZE / 2, &maxValue,
                &maxIndex); // Find max magnitude

    // Convert 2.14 to 8 Bits unsigned
    for (i = 0; i < sizeof(output_knock); i++) {
      uint16_t tmp = (mag_knock[i] / 16384);
      if (tmp > 0xFF)
        tmp = 0xFF;
      output_knock[i] = tmp; // 8 bits minus the 2 fractional bits
    }

    sensors_data.knock_freq = settings.knockFreq;

    if (settings.sensorsInput == SENSORS_INPUT_TEST) {
      sensors_data.knock_value = rand16(0, 255);
      continue;
    }

    sensors_data.knock_value =
        calculateKnockIntensity(settings.knockFreq, settings.knockRatio,
                                FFT_FREQ, output_knock, sizeof(output_knock));
  }
  return;
}

/*
 * CPU Load Monitoring thread.
 */
THD_WORKING_AREA(waThreadMonitor, 128);
static THD_FUNCTION(ThreadMonitor, arg) {
  (void)arg;
  chRegSetThreadName("Monitor");
  uint32_t run_offset, irq_ticks = 0, total_ticks;
  thread_t *tp = NULL;

  DWT->CTRL |= DWT_CTRL_EXCEVTENA_Msk;

  while (TRUE) {
    tp = chRegFirstThread();
    do {
      tp->runtime = 0;
      tp->irqtime = 0;
      tp = chRegNextThread(tp);
    } while (tp != NULL);

    irq_ticks = 0;
    run_offset = DWT->CYCCNT;

    /* Populate load data */
    chThdSleepMilliseconds(1000);

    /* Convert to systick time base */
    total_ticks =
        (DWT->CYCCNT - run_offset) / (STM32_SYSCLK / CH_CFG_ST_FREQUENCY);

    tp = chRegFirstThread();
    do {
      irq_ticks += tp->irqtime;
      tp = chRegNextThread(tp);
    } while (tp != NULL);

    tp = chRegFirstThread();
    do {
      tp->pct = ((tp->runtime * 10000) / total_ticks) | RUNNING(tp);
      tp = chRegNextThread(tp);
    } while (tp != NULL);

    irq_pct = ((irq_ticks * 10000) / total_ticks);
  }
  return;
}

/*
 * Uart1 thread.
 */
THD_WORKING_AREA(waThreadSER1, 256);
CCM_FUNC static THD_FUNCTION(ThreadSER1, arg) {
  (void)arg;
  uint8_t buffer[SERIAL_BUFFERS_SIZE / 2];
  size_t read;
  chRegSetThreadName("MTS");

  while (SD1.state != SD_READY)
    chThdSleepMilliseconds(10);

  while (TRUE) {

    read = sdReadTimeout(&SD1, buffer, 6, TIME_MS2I(40));
    if (read >= 6) {
      readMtsPackets(buffer);
    }
  }
  return;
}
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
int main(void) {
  /*
   * Start OS and HAL
   */

  halInit();
  chSysInit();
  setupIPC();

  DEBUGEN(printf("App Mode\n"));

  usbDisconnectBus(&USBD1);

  /*
   * Initialize extra driver objects.
   */
  sduObjectInit(&SDU1);
  sduObjectInit(&SDU2);

  /*
   * Start peripherals
   */
  sdStart(&SD1, &uart1Cfg);
  sdStart(&SD2, &uart2Cfg);
  sdStart(&SD3, &uart3Cfg);
  usbStart(&USBD1, &usbcfg);
  sduStart(&SDU1, &serusbcfg1);
  sduStart(&SDU2, &serusbcfg2);
  canStart(&CAND1, &cancfg);
  dacStart(&DACD1, &dac1cfg1);
  adcStart(&ADCD1, NULL);
  adcStart(&ADCD3, NULL);
  timcapStart(&TIMCAPD3, &tc_conf);
  pwmStart(&PWMD_LED2, &pwmcfg);

  eeInit();
  // Compare and update versions in EEprom if needed.
  version_t v;
  if (readVersionFromEE(VERSION_IDX_APP, &v) == 0 &&
      memcmp(&versions, &v, sizeof(version_t)) != 0) {

    writeVersionToEE(VERSION_IDX_APP, &versions[VERSION_IDX_APP]);
  }
  if (readVersionFromEE(VERSION_IDX_BL, &v) == 0) {
    memcpy(&versions[VERSION_IDX_BL], &v, sizeof(version_t));
  }

  /*
   * Creates the threads.
   */
  chThdCreateStatic(waThreadBDU, sizeof(waThreadBDU), NORMALPRIO + 5, ThreadBDU,
                    NULL);
  chThdCreateStatic(waThreadSDU, sizeof(waThreadSDU), NORMALPRIO + 2, ThreadSDU,
                    NULL);
  chThdCreateStatic(waThreadADC, sizeof(waThreadADC), NORMALPRIO, ThreadADC,
                    NULL);
  chThdCreateStatic(waThreadKnock, sizeof(waThreadKnock), NORMALPRIO,
                    ThreadKnock, NULL);
  chThdCreateStatic(waThreadCAN, sizeof(waThreadCAN), NORMALPRIO, ThreadCAN,
                    NULL);
  chThdCreateStatic(waThreadSER1, sizeof(waThreadSER1), NORMALPRIO, ThreadSER1,
                    NULL);
  chThdCreateStatic(waThreadRecord, sizeof(waThreadRecord), NORMALPRIO + 1,
                    ThreadRecord, NULL);
  chThdCreateStatic(waThreadWdg, sizeof(waThreadWdg), HIGHPRIO, ThreadWdg,
                    NULL);

  /* Create last as it uses pointers from above */
  chThdCreateStatic(waThreadMonitor, sizeof(waThreadMonitor), NORMALPRIO + 10,
                    ThreadMonitor, NULL);

  while (TRUE) {
    while (USBD1.state != USB_READY)
      chThdSleepMilliseconds(10);

    chThdSleepMilliseconds(100);

    if (usbConnected()) {
      usbConnectBus(&USBD1);
    } else {
      usbDisconnectBus(&USBD1);
    }
  }
}

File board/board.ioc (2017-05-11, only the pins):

Mcu.UserName=STM32F303R(B-C)Tx
PA10.Signal=USART1_RX
PA11.Signal=USB_DM
PA12.Signal=USB_DP
PA13.Signal=SYS_JTMS-SWDIO
PA14.Signal=SYS_JTCK-SWCLK
PA4.GPIO_Label=KNOCK_OFFSET
PA4.Signal=COMP_DAC1_group
PA9.Signal=USART1_TX
PB0.GPIO_Label=SCS_TRIG
PB0.Signal=GPIO_Output
PB1.GPIO_Label=KNK_AN
PB1.Signal=ADC3_IN1
PB12.Signal=SPI2_NSS
PB13.Signal=SPI2_SCK
PB14.Signal=SPI2_MISO
PB15.Signal=SPI2_MOSI
PB3.Signal=USART2_TX
PB4.Signal=USART2_RX
PB5.GPIO_Label=VCC_DETECT
PB5.Signal=GPIO_Input
PB6.GPIO_Label=LED1
PB6.Signal=S_TIM4_CH1
PB7.GPIO_Label=LED2
PB7.Signal=S_TIM4_CH2
PB8.Signal=CAN_RX
PB9.Signal=CAN_TX
PC1.GPIO_Label=AN0
PC1.Signal=ADCx_IN7
PC10.GPIO_Label=KLINE-TX
PC10.Signal=USART3_TX
PC11.GPIO_Label=KLINE-RX
PC11.Signal=USART3_RX
PC12.GPIO_Label=KLINE-CS
PC12.Signal=GPIO_Output
PC15-OSC32_OUT.GPIO_Label=USB_DETECT
PC15-OSC32_OUT.Signal=GPIO_Input
PC2.GPIO_Label=AN1
PC2.Signal=ADCx_IN8
PC3.GPIO_Label=AN2
PC3.Signal=ADCx_IN9
PC6.GPIO_Label=FREQ2_IN
PC6.Signal=S_TIM3_CH1
PC7.GPIO_Label=FREQ1_IN
PC7.Signal=S_TIM3_CH2
PC8.GPIO_Label=USB_CTRL
PC8.Signal=GPIO_Output
PF0-OSC_IN.Signal=RCC_OSC_IN
PF1-OSC_OUT.Signal=RCC_OSC_OUT
PF4.GPIO_Label=BUTTON1
PF4.Signal=GPIO_Input

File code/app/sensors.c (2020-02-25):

#include "sensors.h"
#include "common.h"
#include "ipc.h"
#include "limits.h"
#include "median.h"
#include "protocol.h"
#include "arm_math.h"

/*===========================================================================*/
/* Variables                                                                 */
/*===========================================================================*/

adcsample_t samples_sensors[ADC_GRP1_NUM_CHANNELS * ADC_GRP1_BUF_DEPTH];
adcsample_t samples_knock[ADC_GRP2_NUM_CHANNELS * ADC_GRP2_BUF_DEPTH];
uint8_t output_knock[SPECTRUM_SIZE];

sensors_t sensors_data = {0x0F0F, 0x0F0F, 0x0F0F, 0x0F0F, 0x0F0F,
                          0x0F,   0x0F,   0x0F0F, 0x0F,   0x0F,
                          0x0F,   0x0F,   0x0F,   0x0F,   {0x0F, 0x0F}};
static uint8_t TIM3CC1CaptureNumber, TIM3CC2CaptureNumber;
static uint16_t TIM3CC1ReadValue1, TIM3CC1ReadValue2;
static uint16_t TIM3CC2ReadValue1, TIM3CC2ReadValue2;
static bool TIM3CC1UD, TIM3CC2UD;

/*===========================================================================*/
/* CallBacks                                                                 */
/*===========================================================================*/

CCM_FUNC void reEnableInputCapture(TIMCAPDriver *timcapp) {

  if ((timcapp->tim->DIER & TIM_DIER_CC1IE) == 0) {
    TIM3CC1CaptureNumber = 0;
    TIM3CC1UD = false;
    timcapp->tim->DIER |= TIM_DIER_CC1IE;
  }

  if ((timcapp->tim->DIER & TIM_DIER_CC2IE) == 0) {
    TIM3CC2CaptureNumber = 0;
    TIM3CC2UD = false;
    timcapp->tim->DIER |= TIM_DIER_CC2IE;
  }
}

CCM_FUNC void captureOverflowCb(TIMCAPDriver *timcapp) {
  if (TIM3CC1UD && (timcapp->tim->DIER & TIM_DIER_CC1IE)) {
    timcapp->tim->DIER &= ~TIM_DIER_CC1IE;
    sensors_data.freq1 = 0;
  }

  if (TIM3CC2UD && (timcapp->tim->DIER & TIM_DIER_CC2IE)) {
    timcapp->tim->DIER &= ~TIM_DIER_CC2IE;
    sensors_data.freq2 = 0;
  }

  TIM3CC1UD = true;
  TIM3CC2UD = true;
}

CCM_FUNC void capture1Cb(TIMCAPDriver *timcapp) {
  if (TIM3CC1CaptureNumber == 0) {
    /* Get the Input Capture value */
    TIM3CC1ReadValue1 = timcapp->tim->CCR[0];
    TIM3CC1CaptureNumber = 1;
    TIM3CC1UD = false;
  } else if (TIM3CC1CaptureNumber == 1) {
    uint32_t Capture;
    /* Get the Input Capture value */
    TIM3CC1ReadValue2 = timcapp->tim->CCR[0];
    TIM3CC1UD = false;

    /* Capture computation */
    if (TIM3CC1ReadValue2 > TIM3CC1ReadValue1) {
      Capture = ((uint32_t)TIM3CC1ReadValue2 - (uint32_t)TIM3CC1ReadValue1);
    } else {
      Capture = (((uint32_t)TIM3CC1ReadValue2 + 0x10000) -
                 (uint32_t)TIM3CC1ReadValue1);
    }

    /* Frequency computation */
    sensors_data.freq1 = (tc_conf.frequency / Capture);

    TIM3CC1ReadValue1 = TIM3CC1ReadValue2;
    TIM3CC1CaptureNumber = 0;

    /* Disable CC1 interrupt */
    timcapp->tim->DIER &= ~TIM_DIER_CC1IE;
  }
}

CCM_FUNC void capture2Cb(TIMCAPDriver *timcapp) {
  if (TIM3CC2CaptureNumber == 0) {
    /* Get the Input Capture value */
    TIM3CC2ReadValue1 = timcapp->tim->CCR[1];
    TIM3CC2CaptureNumber = 1;
    TIM3CC2UD = false;
  } else if (TIM3CC2CaptureNumber == 1) {
    uint32_t Capture;
    /* Get the Input Capture value */
    TIM3CC2ReadValue2 = timcapp->tim->CCR[1];
    TIM3CC2UD = false;

    /* Capture computation */
    if (TIM3CC2ReadValue2 > TIM3CC2ReadValue1) {
      Capture = ((uint32_t)TIM3CC2ReadValue2 - (uint32_t)TIM3CC2ReadValue1);
    } else {
      Capture = (((uint32_t)TIM3CC2ReadValue2 + 0x10000) -
                 (uint32_t)TIM3CC2ReadValue1);
    }

    /* Frequency computation */
    sensors_data.freq2 = (tc_conf.frequency / Capture);

    TIM3CC2ReadValue1 = TIM3CC2ReadValue2;
    TIM3CC2CaptureNumber = 0;

    /* Disable CC2 interrupt */
    timcapp->tim->DIER &= ~TIM_DIER_CC2IE;
  }
}

/* Every 64 samples at 965Hz each, triggers at around 15Hz */
CCM_FUNC void sensorsCallback(ADCDriver *adcp) {
  (void)adcp;
  size_t half = (adcp)->depth / 2;
  size_t offset = 0;

  if (!adcIsBufferComplete(adcp)) {
    offset = half;
  }

  // Filtering is done in a dedicated thread
  chSysLockFromISR();
  allocSendSamplesI(&sensorsMb, (void *)(adcp->samples + offset), half);
  chSysUnlockFromISR();
}

/* Every 1024 samples at 117.263KHz each, triggers at around 114Hz */
CCM_FUNC void knockCallback(ADCDriver *adcp) {
  (void)adcp;
  size_t half = (adcp)->depth / 2;
  size_t offset = 0;

  if (!adcIsBufferComplete(adcp)) {
    offset = half;
  }

  // Do FFT + Mag in a dedicated thread
  chSysLockFromISR();
  allocSendSamplesI(&sensorsMb, (void *)(adcp->samples + offset), half);
  chSysUnlockFromISR();
}

/*===========================================================================*/
/* Configs                                                                   */
/*===========================================================================*/

TIMCAPConfig tc_conf = {{TIMCAP_INPUT_ACTIVE_HIGH, TIMCAP_INPUT_ACTIVE_HIGH,
                         TIMCAP_INPUT_DISABLED, TIMCAP_INPUT_DISABLED},
                        200000, /* TIM3 Runs at 36Mhz max. (1/200000)*65536 =
                                   0.32s Max, 3.12Hz Min */
                        {capture1Cb, capture2Cb, NULL, NULL},
                        captureOverflowCb,
                        0,
                        0};

/* ADC12 Clk is 72Mhz/128 562KHz  */
const ADCConversionGroup adcgrpcfg_sensors = {
    TRUE,
    ADC_GRP1_NUM_CHANNELS,
    sensorsCallback,
    NULL,
    ADC_CFGR_CONT,                           /* CFGR    */
    ADC_TR(0, 4095),                         /* TR1     */
    {                                        /* SMPR[2] */
     ADC_SMPR1_SMP_AN7(ADC_SMPR_SMP_181P5) | /* Sampling rate =
                                                562000/(61.5+12.5) = 2.9KHz  */
         ADC_SMPR1_SMP_AN8(
             ADC_SMPR_SMP_181P5) | /* 7.56Khz for 3 channels = 965Hz */
         ADC_SMPR1_SMP_AN9(ADC_SMPR_SMP_181P5),
     0},
    {/* SQR[4]  */
     ADC_SQR1_SQ1_N(ADC_CHANNEL_IN7) | ADC_SQR1_SQ2_N(ADC_CHANNEL_IN8) |
         ADC_SQR1_SQ3_N(ADC_CHANNEL_IN9) | 0,
     0, 0, 0}};

/* ADC34 Clk is 72Mhz/1 72Mhz  */
const ADCConversionGroup adcgrpcfg_knock = {
    TRUE,
    ADC_GRP2_NUM_CHANNELS,
    knockCallback,
    NULL,
    ADC_CFGR_CONT | ADC_CFGR_ALIGN, /* CFGR - Align result to left (convert 12
                                       to 16 bits) */
    ADC_TR(0, 4095),                /* TR1     */
    {
        /* SMPR[2] */
        ADC_SMPR1_SMP_AN1(
            ADC_SMPR_SMP_601P5), /* Sampling rate = 72000000/(601.5+12.5) =
                                    117.263Khz  */
        0,
    },
    {/* SQR[4]  */
     ADC_SQR1_SQ1_N(ADC_CHANNEL_IN1), 0, 0, 0}};
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

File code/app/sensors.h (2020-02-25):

#ifndef SENSORS_H
#define SENSORS_H

#include "common.h"
#include "hal.h"
#include "ipc.h"
#include "median.h"
#include "protocol.h"

#define ADC_GRP1_NUM_CHANNELS 3
#define ADC_GRP1_BUF_DEPTH 128

#define ADC_GRP2_NUM_CHANNELS 1
#define ADC_GRP2_BUF_DEPTH 2048

#define VREF 3300
#define AN_RATIO \
    1.22f /* 5000mV/4096 voltage divider ratio is 1.22 (10K/2k=1.5) */
#define VBAT_RATIO                                        \
    13.42f /* 55000mV/4096 voltage divider ratio is 13.42 \
              (100K/10K=11)+(1K/2K=1.5) */

extern adcsample_t samples_sensors[ADC_GRP1_NUM_CHANNELS * ADC_GRP1_BUF_DEPTH];
extern adcsample_t samples_knock[ADC_GRP2_NUM_CHANNELS * ADC_GRP2_BUF_DEPTH];
extern uint8_t output_knock[SPECTRUM_SIZE];

extern const ADCConversionGroup adcgrpcfg_sensors;
extern const ADCConversionGroup adcgrpcfg_knock;

extern sensors_t sensors_data;
extern TIMCAPConfig tc_conf;
extern uint16_t irq_pct;
extern const char* irq_name;

void reEnableInputCapture(TIMCAPDriver* timcapp);

uint8_t calculateTpFromMillivolt(uint16_t AnMin, uint16_t AnMax,
    uint16_t AnVal);
uint8_t calculateAFRFromMillivolt(uint16_t afrMin, uint16_t afrMax,
    uint16_t AnVal);
uint16_t calculateFreqWithRatio(uint16_t freq, float ratio);
uint8_t calculateKnockIntensity(uint16_t tgtFreq, uint16_t ratio,
    uint16_t smplFreq, uint8_t* buffer,
    uint16_t size);

#endif

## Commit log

2014-04-05 Adding TVS Diode
    [board.brd, board.sch]
2014-04-06 TVS Diode changes, Adding pull-ups to K-line, updated K-line IC
    [board.brd, board.sch]
2014-04-06 Minor fixes
    [board.brd]
2014-04-08 Adding HSE Crystal, needed for USB.
    [board.brd, board.sch]
2014-04-08 Forgot to re-enable tPlace layer.
    [board.brd]
2014-04-19 [Board] Adding output for external relay
    [board.brd, board.sch]
2014-04-19 [Board] Updated parts references
    [board.brd, board.sch]
2014-04-19 [Board] Updated USB with esd/tvs protection, and vbus detection
    [board.brd, board.sch]
2014-04-20 [Board] Adding/Fixing USB detection and control
    [board.brd, board.sch]
2014-04-21 [Code] Edited board files
2014-04-21 Adding board.h generation script
2014-04-21 Adding missing board_gpio.h file
2014-04-25 [Board] Renaming for rev A
    [board_revA.brd, board_revA.sch]
2014-04-25 [Code] Adding more pins define in board.h
2014-04-26 [Board] Adding Rev B
    [board_revB.brd, board_revB.sch]
2014-04-26 [Board Rev B] Changed switch to a more common model using metric pitch
    [board_revB.brd, board_revB.sch]
2014-04-27 [GUI - BL] Moving bootloader class to its own thread to use signals
2014-04-28 [GUI - BL] Cleaning threads implementation, now closing properly.
2014-04-30 [GUI] Adding fields for displaying sensors values. [GUI] Preparing QUndo.
2014-05-01 [GUI] Adding translation support
    [board_revB.brd, board_revB.sch]
2014-05-01 [code] Adding a common linker script that we include in both projects
    [board_revB.brd]
2014-05-02 [code] Fixed user app so that it compiles. (still does nothing)
    [main.c]
2014-05-02 [code] Adding a dummy usb serial thread that just reads data
2014-05-02 [code] Basic USB to UART serial bridge
2014-05-03 [Board Rev B] Updated additional UART interface
    [board_revB.brd, board_revB.sch]
2014-05-03 [Board Rev B] Adding another switch
    [board_revB.brd, board_revB.sch]
2014-05-05 [Board Rev B] Moving the decoupling caps closer
    [board_revB.brd]
2014-05-07 [GUI] Working on shortcuts and undo.
    [spinbox.cpp]
2014-05-08 [Board Rev B] Spacing some 0603s
    [board_revB.brd]
2014-05-09 [GUI] Fixed Undo for spinboxes
    [spinbox.cpp]
2014-05-12 [Board Rev A] Tweaking resistor values
    [board_revA.brd, board_revA.sch]
2014-05-23 [Board Rev A] Tweaking capacitor values
    [board_revA.brd, board_revA.sch]
2014-05-27 [GUI] Working on FW update wizard [Board] Updated URL [CODE] Small workarounds on the bootloader until I get the hardware fixed.
    [board_revA.brd, board_revB.brd]
2014-06-08 [Code/GUI] Adding ADC routines [GUI] Removing webkit
2014-06-08 [Gui/Code] Still working on ADC stuff.
2014-06-09 [Code] Working on timer bugs.
    [main.c, sensors.c, sensors.h]
2014-06-11 [GUI] Moving update thread to Motolink class + QThread
2014-06-11 [GUI/Code] debugging USB crashes
    [main.c, sensors.c, sensors.h]
2014-06-15 [Code] Crashes are fixed. Bootloader updated to use switch. The problem was waiting for events in the BDU thread would prevent the IWDG thread to work and trigger a reset. Moved IWDG refreshing to an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
    [common.c, main.c]
2014-06-15 [Code] Bootloader improvements and fixes.
    [halconf.h, main.c]
2014-06-16 [Code] Add some code for knock ADC handling.
2014-06-17 [Code] Fixed ADC clocks.
    [main.c, sensors.c, sensors.h]
2014-06-18 [Code] Adding CAN Bus thread.
2014-06-19 [Code] Fixed Dac driver (missing init)
    [main.c]
2014-06-19 [Code] Increased sensors buffer.
2014-06-20 [Code] Tweaking ADC values.
2014-06-21 [Code] Frequency capture working. Updated board script.
2014-06-22 [GUI] Fixed linux version (PID/VIP were swapped)
2014-06-22 [Code] Working on DAC driver improvements.
2014-06-22 [Code] Updated external drivers model.
2014-06-23 [Code] Moving drivers to submodule.
2014-06-23 [Code] Updated DAC driver.
2014-06-23 [Code] Updating DAC driver.
2014-06-23 [Code] DAC driver update.
2014-06-23 [Code] Updating DAC related code and other minor things.
    [board_revB.brd]
2014-06-23 [Board Rev B] Multiple improvements. Adding extra UART.
    [board_revB.brd, board_revB.sch]
2014-06-23 [Code] Updating mx2board.py and board file for uart2.
2014-06-25 [Code] Adding missing brackets.
    [main.c]
2014-06-27 [Code] Adding echo check to serial thread.
2014-06-27 Adding Windows drivers installers.
2014-06-27 [Code] Updating drivers submodule.
2014-06-27 [Code] Changed serial thread leds.
2014-06-29 [Board Rev B] Updating various components.
    [board_revB.brd, board_revB.sch]
2014-06-29 [Board Rev B] USB connector renamed.
    [board_revB.brd, board_revB.sch]
2014-07-07 [Board Rev B] Adding voltage reference for VDDA.
    [board_revB.brd, board_revB.sch]
2014-08-01 [Board Rev B] Adding an EEPROM
2014-08-04 [Board] Fix files
    [board_revB.brd, board_revB.sch]
2014-08-04 [Board] Layout improvements
    [board_revB.brd, board_revB.sch]
2014-08-16 [Code/GUI] Tested/Fixed knock spectrum graph.
    [main.c, sensors.c, sensors.h]
2014-08-17 [Code] Fixed max knock voltage.
2014-08-21 [Code/GUI] Fixed knock signal scale.
    [board.ioc, main.c, sensors.c]
2014-08-22 [Code/GUI] Adding median filter Optimizing ADC samples.
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2014-10-21 Fixed ADC
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2014-10-30 [GUI] Working on XML file saving
    [board_revB.brd, board_revB.sch]
2014-11-05 [GUI/Code] Rewrote DSP functions, switched to float; Updated DSP library
    [board_revA.brd, board_revA.sch, board_revB.brd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]
2014-11-06 [GUI] Adding basic header editor, [Code] Moving thread stacks to CCM.
2014-11-09 [GUI] real time cell tracking implemented, [Code] Reworked median filter code
    [common.c, main.c]
2014-11-12 [Code] Fixed median filter and frequency counter
    [main.c, sensors.c, sensors.h]
2014-11-13 [Code] Fixed ADC values
    [main.c, sensors.c, sensors.h]
2014-11-13 [Board A] Fixed resistor values
    [board_revA.brd, board_revA.sch]
2014-11-14 [Code] Now using CCM for ISRs and time critical threads
    [board_revB.brd, board_revB.sch]
2014-11-15 [GUI] Adding sensors widget refresh timer to descrease cpu load (refreshes were too fast)
2015-01-16 [Board] Updates
    [board_revB.brd, board_revB.sch]
2015-01-19 [Code] Adding K-line init to SDU thread.
2015-01-25 [Code] Adding K-line CS pin handling
2015-08-20 [code] Missing serial defines
    [halconf.h, mcuconf.h]
2015-08-20 [code] Fixes for chibios 3.0 stable
    [main.c]
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2015-08-24 [Code/GUI] Updating qcustomplot and fixing bootloader missing config
    [main.c]
2015-09-06 [code] updated ChibiOS
    [board_revB.brd, board_revB.sch]
2015-09-06 [Board] Working on Rev B
    [board_revB.brd, board_revB.sch]
2015-10-17 [Board] working on rev B (full rework)
    [board_revB.brd, board_revB.sch]
2015-10-31 [Board] working on rev B (routing)
    [board_revB.brd, board_revB.sch]
2015-11-16 [Board] working on rev B (routing/schema)
    [board_revB.brd, board_revB.sch]
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2015-12-21 [Board] working on rev B (routing/cleaning)
    [board_revB.brd, board_revB.sch]
2016-01-18 [Code] Made changes to work with rev B board (uses different pins/peripherals)
2016-01-19 [Code] Updating mx2board script config
    [board_revB.brd, board_revB.sch]
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2016-01-20 [code] cleaning and updating script to generate more defines for timers.
2016-01-27 Fixing bootloader to work with latest Chibios (16.1)
    [halconf.h, main.c]
2016-01-30 [Code] Updates/Fixes for ChibiOS 16.1
    [main.c]
2016-01-31 [Code] Fixed vectors table
    [board.c]
2016-02-01 [code] Fixed App for Chibi 16.1
    [halconf.h, main.c, mcuconf.h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]
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2016-02-03 [Code] Fixed main app
    [main.c, mcuconf.h, sensors.c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]
2016-02-04 [Code/GUI] Fixed/Tested dynamic thread monitoring
    [main.c]
2016-02-04 [Code] Fixes for storage
    [main.c, storage.c]
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2016-02-12 [Code] Working on storage (Fixed)
    [main.c, storage.c]
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2017-02-16 [code] Adding base CANBUS functions. Will need some testing.
2017-02-18 [gui/code] Various minor fixes
    [main.c, sensors.c]
2017-02-19 Removing drivers since we don't need them anymore.
2017-02-20 [code] Fixed version eeprom function [GUI] Optimised version functions
    [main.c, storage.c]
2017-04-16 [Code] Reverting to WINUSB QtUSB, cleaning structs
    [main.c]
2017-04-19 [code] Fixed analog ratios
    [sensors.h]
2017-04-20 [code] Fixing settings struct
    [storage.c]
2017-04-21 [code] Fixed tables recording and a bunch of other things
    [main.c, storage.c]
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2017-04-24 [code] Fixed analog AFR calculation.
    [sensors.c]
2017-04-25 [code] Fixed recording (page too small) [code] Adding test mode [GUI] Improved cell calc/redraw
    [board.c, common.c, main.c]
2017-04-25 [code] Fixed TPS test values
    [main.c]
2017-04-25 [code] Fixed test knock value. [GUI] Changed knock table range (for colors)
    [main.c]
2017-04-30 [all] Fixed OBD (CanBus) emulator.
    [board_revB.brd, board_revB.sch]
2017-05-05 [code] Cleaning MTS, Fixed K-LINE
    [common.c, main.c]
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2017-05-07 [code] Fixed RPM table lookup [GUI] Updated refresh speed to 40hz
    [halconf.h, main.c]
2017-05-07 [code] Fixed bootloader compile error.
    [main.c, mcuconf.h]
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2020-02-24 Fixes for Chibios 19.1.x
    [board.c, common.c, halconf.h]
2020-02-25 Code: Fixed include guard and types
    [main.c]

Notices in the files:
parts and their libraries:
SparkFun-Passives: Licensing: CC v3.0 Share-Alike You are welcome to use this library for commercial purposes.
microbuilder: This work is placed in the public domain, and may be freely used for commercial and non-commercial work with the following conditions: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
